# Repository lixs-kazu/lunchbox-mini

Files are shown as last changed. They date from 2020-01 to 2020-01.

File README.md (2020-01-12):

# lunchbox-mini

40(48)キーの小型キーボード

トッププレートにもpro microのフットプリントを配置することによってchocスイッチが使用可能

ble micro proを使用した際に簡単にBLE接続先に接続できるようにタクトスイッチをキーボード側面に配置

通常のpro microも使用できるようにTRRSコネクタを配置（I2Cには対応してません）

キーピッチは縦・横ともに19mmなのでキーキャップを削る必要はありません

# ビルドガイド

スイッチをつける前にTRRSコネクタとRESET用のタクトスイッチをつける以外は他のキーボードと同じです。

ファームはありません。（一応helixと同じpin配置にしてあるのでhelixのファームが使用できます。）

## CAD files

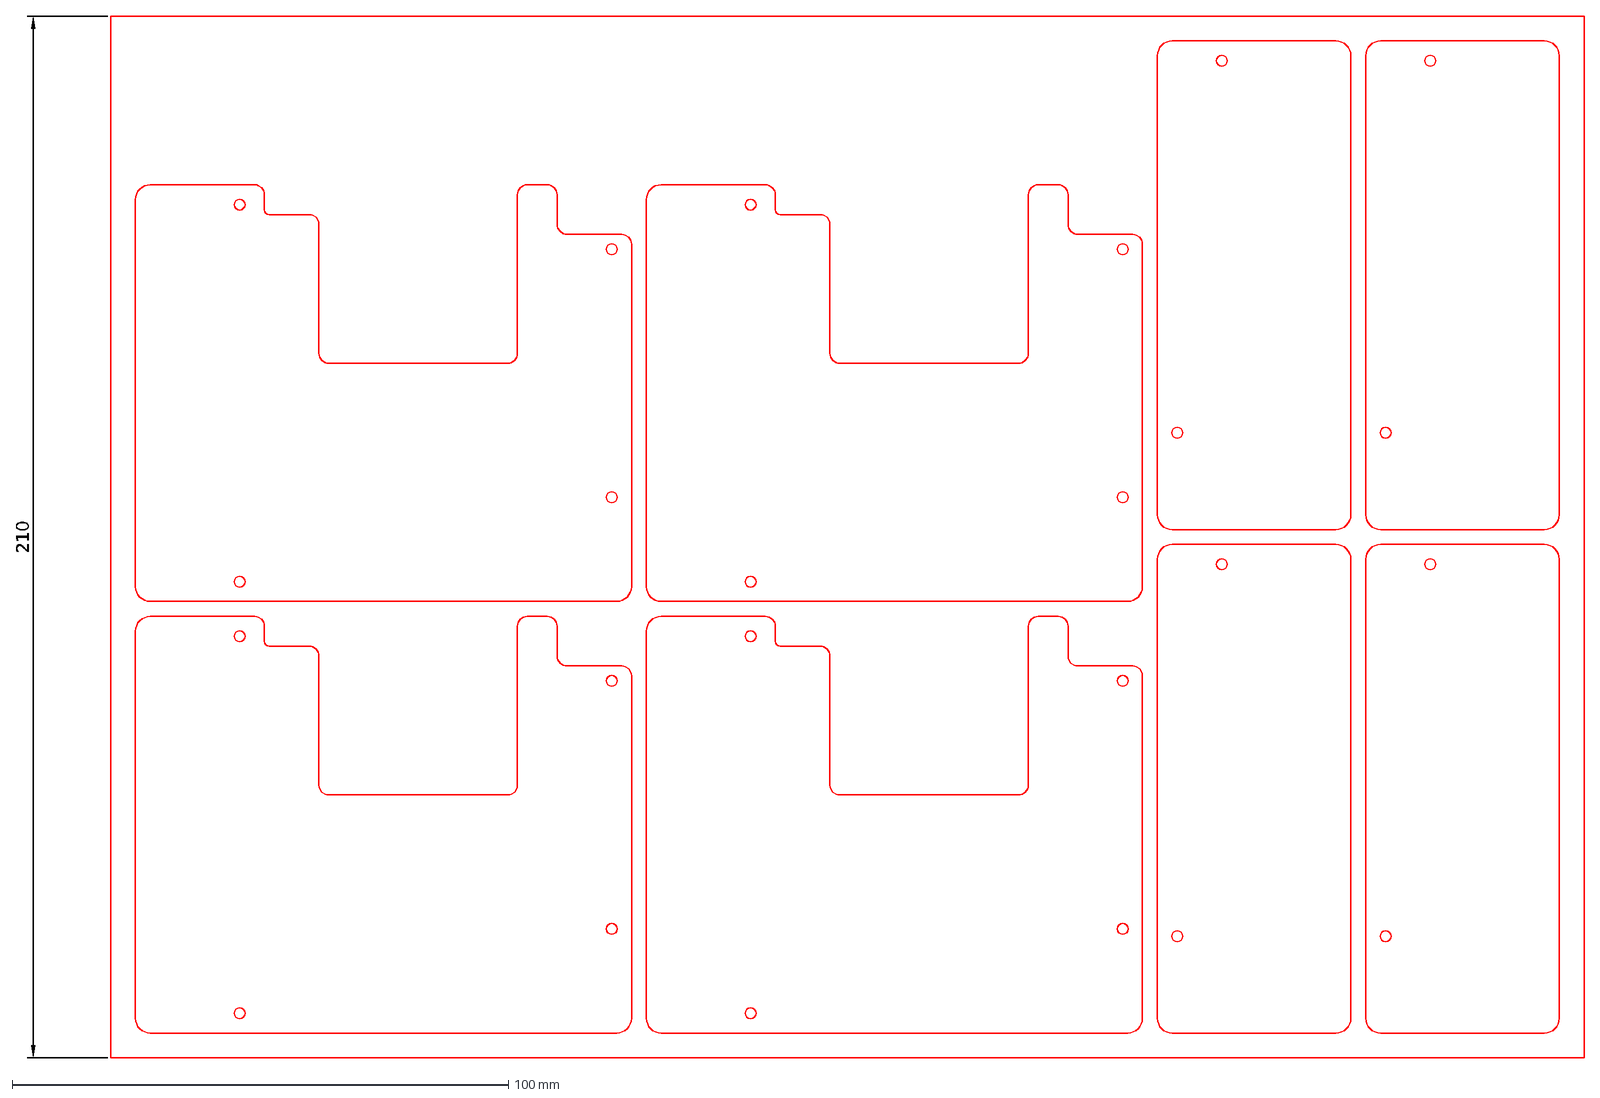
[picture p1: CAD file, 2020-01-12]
lunchbox-mini/bottom-plate/100cm^2-A4.dxf
210

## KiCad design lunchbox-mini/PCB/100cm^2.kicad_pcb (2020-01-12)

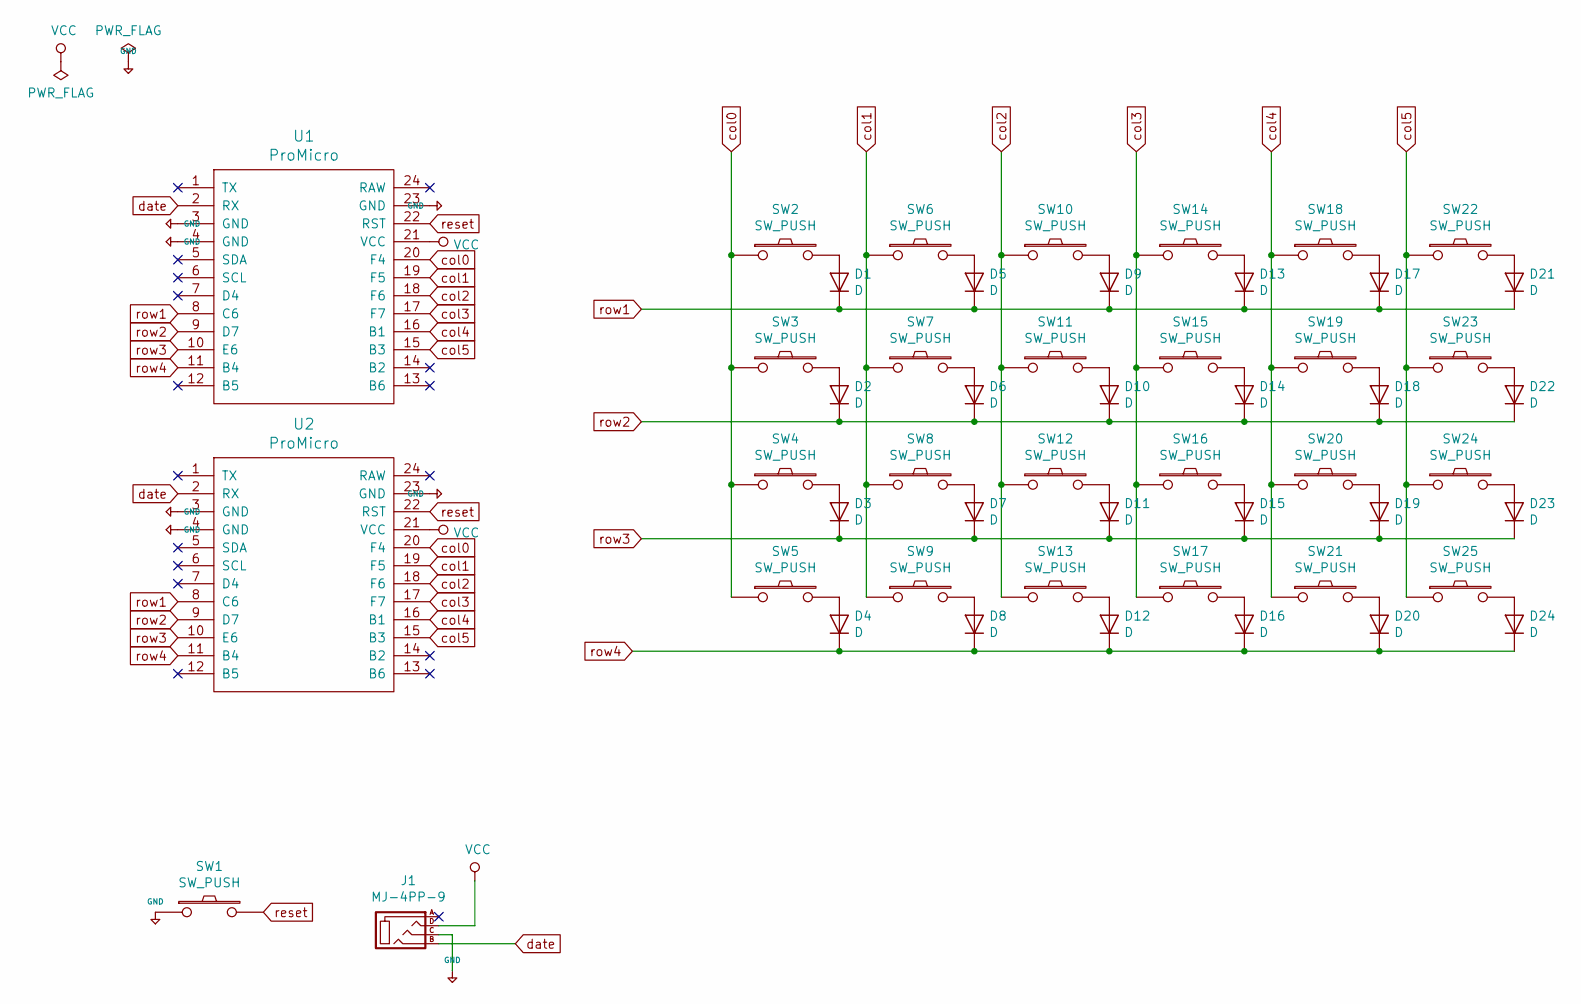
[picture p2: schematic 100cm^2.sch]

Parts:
D1, D2, D3, D4, D5, D6, D7, D8, D9, D10, D11, D12, D13, D14, D15, D16, D17, D18, D19, D20, D21, D22, D23, D24: D; D3_SMD
J1: MJ-4PP-9
SW1, SW22, SW23, SW24, SW25: SW_PUSH; ResetSW
SW2, SW3, SW4, SW5, SW6, SW7, SW8, SW9, SW10, SW11, SW12, SW13, SW14, SW15, SW16, SW17, SW18, SW19, SW20, SW21: SW_PUSH; MX_PG1350_FLIP_HOLES
U1, U2: ProMicro; ProMicro_v2_1side

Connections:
+5V: J1.C, SW1.1, U1.3 (GND), U1.4 (GND), U1.23 (GND), U2.3 (GND), U2.4 (GND), U2.23 (GND)
unnamed: D1.2 (A), SW2.2
unnamed: D2.2 (A), SW3.2
unnamed: D3.2 (A), SW4.2
unnamed: D4.2 (A), SW5.2
unnamed: D5.2 (A), SW6.2
unnamed: D6.2 (A), SW7.2
unnamed: D7.2 (A), SW8.2
unnamed: D8.2 (A), SW9.2
unnamed: D9.2 (A), SW10.2
unnamed: D10.2 (A), SW11.2
unnamed: D11.2 (A), SW12.2
unnamed: D12.2 (A), SW13.2
unnamed: D13.2 (A), SW14.2
unnamed: D14.2 (A), SW15.2
unnamed: D15.2 (A), SW16.2
unnamed: D16.2 (A), SW17.2
unnamed: D17.2 (A), SW18.2
unnamed: D18.2 (A), SW19.2
unnamed: D19.2 (A), SW20.2
unnamed: D20.2 (A), SW21.2
unnamed: D21.2 (A), SW22.2
unnamed: D22.2 (A), SW23.2
unnamed: D23.2 (A), SW24.2
unnamed: D24.2 (A), SW25.2
VCC: J1.D, U1.21 (VCC), U2.21 (VCC)
col0: SW2.1, SW3.1, SW4.1, SW5.1, U1.20 (F4), U2.20 (F4)
col1: SW6.1, SW7.1, SW8.1, SW9.1, U1.19 (F5), U2.19 (F5)
col2: SW10.1, SW11.1, SW12.1, SW13.1, U1.18 (F6), U2.18 (F6)
col3: SW14.1, SW15.1, SW16.1, SW17.1, U1.17 (F7), U2.17 (F7)
col4: SW18.1, SW19.1, SW20.1, SW21.1, U1.16 (B1), U2.16 (B1)
col5: SW22.1, SW23.1, SW24.1, SW25.1, U1.15 (B3), U2.15 (B3)
date: J1.B, U1.2 (RX), U2.2 (RX)
reset: SW1.2, U1.22 (RST), U2.22 (RST)
row1: D1.1 (K), D5.1 (K), D9.1 (K), D13.1 (K), D17.1 (K), D21.1 (K), U1.8 (C6), U2.8 (C6)
row2: D2.1 (K), D6.1 (K), D10.1 (K), D14.1 (K), D18.1 (K), D22.1 (K), U1.9 (D7), U2.9 (D7)
row3: D3.1 (K), D7.1 (K), D11.1 (K), D15.1 (K), D19.1 (K), D23.1 (K), U1.10 (E6), U2.10 (E6)
row4: D4.1 (K), D8.1 (K), D12.1 (K), D16.1 (K), D20.1 (K), D24.1 (K), U1.11 (B4), U2.11 (B4)

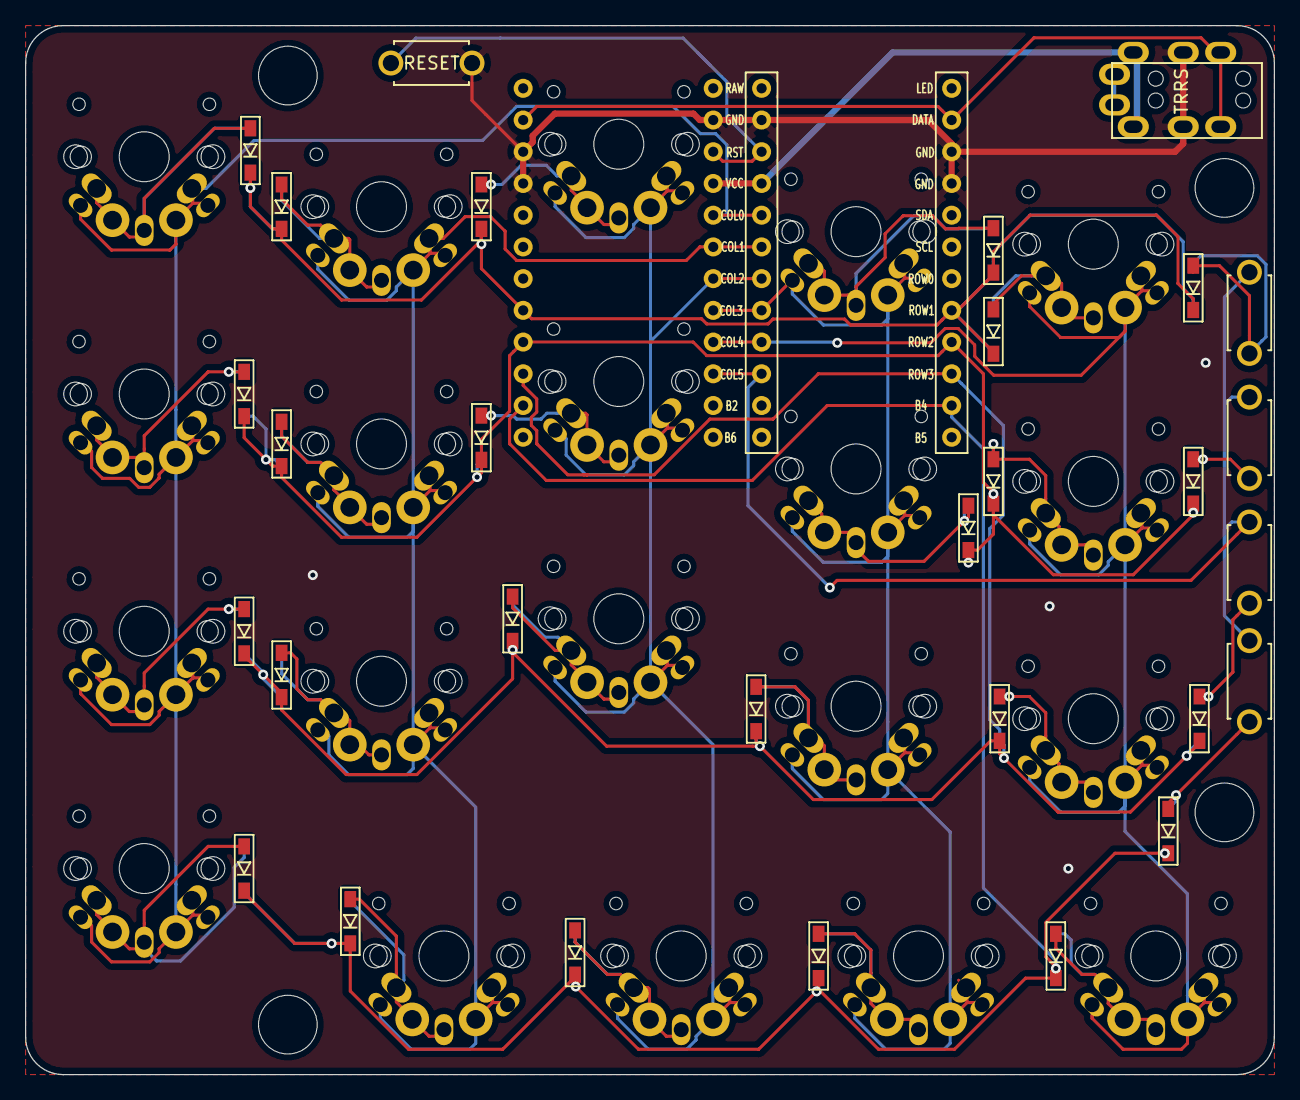
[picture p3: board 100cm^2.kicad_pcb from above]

Board: 2 copper layers, 100.0 x 84.0 mm, 56 parts (1 on the bottom side), 38 nets.

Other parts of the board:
HOLE_3M, HOLE_3M#2, HOLE_3M#3, HOLE_3M#4: VAL**; HOLE_M2_TH
